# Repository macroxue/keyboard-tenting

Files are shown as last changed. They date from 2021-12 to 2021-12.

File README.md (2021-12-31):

# Continuously Variable Tenting (CVT)

This is a solution for flexible and reliable tenting of keyboards with very low
cost. Below is a short video showing it in action. A DIYer who has access to
3D-printing can easily build it and customize it.

https://user-images.githubusercontent.com/1887856/147719232-e44d4478-9f9e-47b6-bbbc-71b62043c802.mp4

## The Structure

The structure is essentially a steel plate on a
[ball joint](https://en.wikipedia.org/wiki/Ball_joint).
Any keyboard with magnets at the back can attach to the steel plate so it's a
universal platform. The ball joint allows the plate to rotate continuously in
a certain range so it's easy to tent and tilt the keyboard to one's liking.

## Parts

 * One 6"x12" stainless steel sheet, 0.03" or slightly thicker
 * Two 3D-printed ball joints
 * Four 1.25" binder clips
 * Eight 10mm disc magnets or two refrigerator magnets of playing card size

## Tools

 * A ruler and a pen
 * Heavy duty scissors
 * A file or sandpaper
 * 3D printer
 * Paper
 * Super glue
 * A candle and a lighter
 * Tape

## Installing Magnets

For a quick experiment, refrigerator magnets can be taped to the back of the
keyboard. 

For a permanent installation, I electric-taped disc magnets inside the keyboard's 
case, one at each corner. It works perfectly since the case has a thin (1.5mm) 
bottom and is very light. A large/heavy keyboard may need more or larger magnets. 
Have magnets oriented the same way, all north poles up or all north poles down. 

Test the installation on the steel sheet, vertically and upside down. If
needed, a few magnets can be attached to the back side of the sheet to help the
keyboard stay in place.

## Cutting the Steel Sheet

The plate can be of any shape/size as long as the keyboard can stay on it. (One can
even repurpose steel salad plates for this.) For simplicity, I would just go with a 
rectangle with rounded corners, because that's about as much as I could do using 
heavy duty scissors. Use a ruler and a pen to mark the line to cut. Be careful that
the sheet could be too hard to cut or too easy to distort. Test-cutting near
the edge could be a good idea. Be sure to file/sand down the rough edges afterwards.

By default, the model assumes the plate is 6 inches in length and shorter in width.
If a significantly larger geometry is desired, one needs to change the 3D model
in [cvt.scad](https://github.com/macroxue/keyboard-tenting/blob/master/cvt.scad)
accordingly to avoid the plate touching the desk when tented at the maximal angle.

## Printing the Ball Joint

ball-joint

Print either [cvt-35.stl](https://github.com/macroxue/keyboard-tenting/blob/master/cvt-35.stl)
for 35 degree of tenting maximally or
[cvt-45.stl](https://github.com/macroxue/keyboard-tenting/blob/master/cvt-45.stl) for 45
degree. The 35-degree one is slightly shorter than the 45-degree one, if that
matters. Each print produces three pieces for one hand, so the same model needs
to be printed twice. It takes about 12 hours to finish two prints on my
FlashForge Creator Pro.

My prints are with ABS filament. Other material should work too but I didn't
verify. A bit later melted wax will go into the socket so the material must
withstand the heat and not deform.

One can also modify [cvt.scad](https://github.com/macroxue/keyboard-tenting/blob/master/cvt.scad)
to customize the print, which is rendered by [OpenSCAD](https://openscad.org/). Please pay attention to
comments in the model and visually examine the rendered output for any issues
with structural integrity. The ball may need supports near the base if the
overhang is more than 45 degree. It can be a good idea to test-print a 50% model
after significant changes.

The two socket pieces may need to be polished to close the socket well.
Clamp the two pieces together by the binder clips. If the socket wobbles on
a smooth surface when slightly touched, it should be fixed and the protruding
parts can be scratched off by a knife. This usually happens around the edge
touching the printer's bed.

50-percent

## Gluing the Ball to the Plate

Put the ball at the center of the plate and wrap a paper stripe (1" to 2" wide)
around it.  Tape the paper cylinder to the plate and take the ball out.
Drop the ball with the flat side down into the cylinder and it should land
perfectly at the desired location. Apply super glue to the flat side and drop
the ball the same way again. Press the ball down slightly so the glue is more
evenly distributed.  Let it sit for a minute and the ball is permanently glued
to the plate.

## Waxing the Socket

Put all things together, the ball in the socket and the socket clamped by
binder clips. Try turning the plate to see how tight the joint is. Most likely
it's a bit loose. If so, take the ball out and light a candle. Drip melted wax
into the socket and spread it on the surface. If the socket can't close well
after this, just scratch some wax off. Test the tightness and repeat until it's
about right.

## Stablizing the Joint

All 3D-printed objects are slippery on a smooth surface. My solution is to put
the joint on a rubber mat. Another way is to rubber-coat its bottom with Plasti
Dip, but the process could be a little hazardous, requiring mask and glove protection.

## Tenting the keyboard

Put the keyboard on the plate. Adjust the orientation of the keyboard by
rotating the ball joint like how it's done in the video and see if any fine
tuning is needed.

To find the most comfortable position, one can quickly move or rotate the keyboard
on the plate without adjusting the ball joint every time.

Decorate them to show some personality if you like.

launch

## Acknowledgment

Many thanks to reditters of [r/ErgoMechBoards](https://www.reddit.com/r/ErgoMechKeyboards/)
who contributed to the discussion of the design in these threads.
* https://www.reddit.com/r/ErgoMechKeyboards/comments/ropcwq/continuously_variable_tenting_ball_joint_steel/
* https://www.reddit.com/r/ErgoMechKeyboards/comments/rqv95e/a_prototype_of_cvt_continuously_variable_tenting/

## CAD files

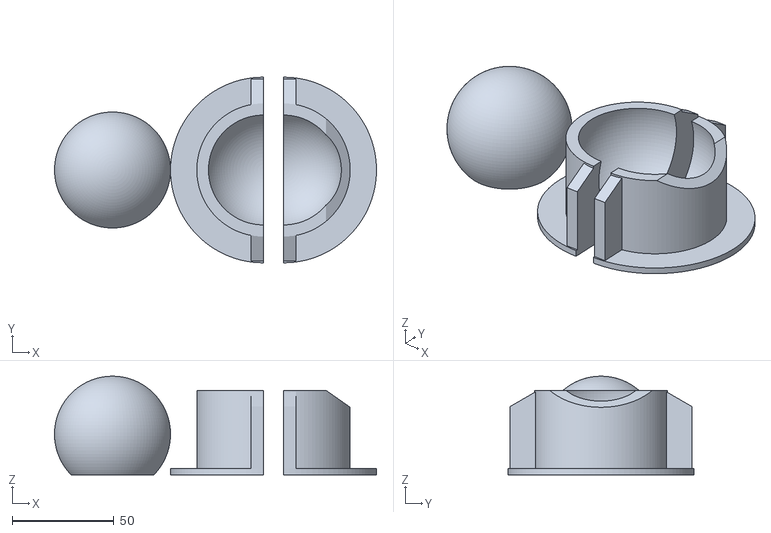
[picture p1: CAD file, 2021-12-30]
cvt-35.stl
158.6 x 91.4 x 48.6

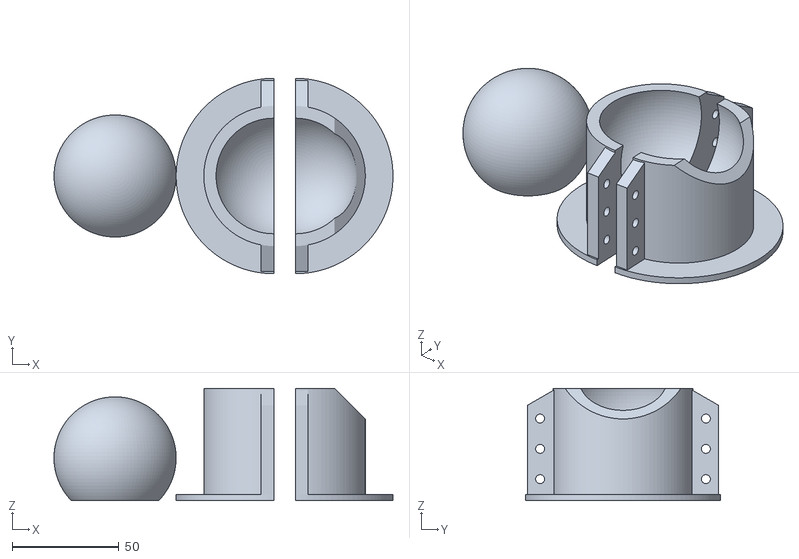
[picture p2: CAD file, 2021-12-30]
cvt-45.stl
158.6 x 91.4 x 52.6

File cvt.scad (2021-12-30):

// Higher tenting degree may produce a taller structure.
max_tenting_degree = 35;

// Plate to attach to the ball.
plate_length = 25.4 * 6;
plate_width = 25.4 * 4.5;

// The ball in the ball joint. A larger ball provides better stability but increases
// the height of the structure.
ball_radius = 25.4 * 1.125;
// The plateau supporting the plate. If the area is too small, the plate may flex.
// The default gives about 45 degree overhang at the base so it can be printed
// without supports.
ball_cut_ratio = 0.3;
ball_plateau_height = ball_radius * (1 - ball_cut_ratio);

// The lowest point that the plate can reach, assuming the plate is not rotated
// on the Z-axis. This inputs to the socket's height.
plate_lowest_z = plate_length / 2 * sin(-max_tenting_degree) +
                 ball_plateau_height * cos(-max_tenting_degree);

// Space between the ball and the socket. Could be 0 if the printer is very precise.
// Here we just want the socket to close well around the ball.
space = 0.2;

// Geometry of the socket.
socket_radius = ball_radius + space;
socket_closing_degree = 20;  // to prevent the ball from escaping
socket_thickness = 4;
socket_depth = socket_radius * (1 + sin(socket_closing_degree));
socket_height =
    max(socket_radius, -plate_lowest_z) + socket_radius * sin(socket_closing_degree);
socket_base_height = socket_height - socket_depth;

// The disc at the bottom to provide stability.
disc_radius = ball_radius * 1.6;
disc_thickness = 3;

// The number of sides to render a circle.
$fn = 100;
// The extra cut for difference() so the cut is unambiguous.
d = 0.1;
// Pseudo-infinity for splitting the socket into two parts.
inf = 999;

module plate(height = socket_radius) {
  translate([ -plate_length / 2, -plate_width / 2, ball_plateau_height ])
      cube([ plate_length, plate_width, height ]);
}

module ball() {
  difference() {
    sphere(r = ball_radius);
    translate([ 0, 0, ball_plateau_height ])
        cylinder(r = ball_radius, h = ball_radius * ball_cut_ratio);
  }
}

module socket() {
  difference() {
    translate([ 0, 0, -socket_radius - socket_base_height ]) union() {
      cylinder(r = socket_radius + socket_thickness, h = socket_height);

      // Ledges for binder clips.
      ledge_length = socket_thickness * 3;
      ledge_width = socket_thickness * 4;
      for (degree = [ 0, 180 ]) {
        rotate([ 0, 0, degree ])
            translate([ -ledge_length / 2, -socket_radius - ledge_width, 0 ]) {
          difference() {
            cube([ ledge_length, ledge_width, socket_height ]);
            translate([ -d, 0, socket_height - ledge_width * sin(30) ])
                rotate([ 30, 0, 0 ])
                    cube([ ledge_length + d * 2, ledge_width, socket_height ]);
          }
        }
      }
    }
    sphere(r = socket_radius);
    rotate([ 0, max_tenting_degree, 0 ]) plate();
  }
  translate([ 0, 0, -socket_radius - socket_base_height ]) disc();
}

module socket_left() {
  difference() {
    socket();
    translate([ 0, -inf / 2, -inf / 2 ]) cube([ inf, inf, inf ]);
  }
}

module socket_right() {
  difference() {
    socket();
    translate([ -inf, -inf / 2, -inf / 2 ]) cube([ inf, inf, inf ]);
  }
}

module disc() {
  translate([ 0, 0, -disc_thickness ]) cylinder(r = disc_radius, h = disc_thickness);
}

module pieces() {
  translate([ 0, 0, -ball_radius * ball_cut_ratio - socket_base_height ])
      rotate([ 180, 0, 0 ]) ball();
  translate([ disc_radius + ball_radius, 0, disc_thickness + space ]) socket_left();
  translate([ disc_radius + ball_radius + 10, 0, disc_thickness + space ]) socket_right();
}

module assembly(tent = max_tenting_degree, tilt = 0) {
  rotate([ 0, tent, 0 ]) rotate([ 0, 0, tilt ]) {
    ball();
    plate(1);
  }
  socket();
}

module animation() { assembly($t * max_tenting_degree, $t * -30); }

// Pieces to be printed.
translate([ plate_length / 2 + ball_radius, 0, 0 ]) pieces();

// Uncomment to see the assembly of pieces.
// assembly();

// Uncomment to see the rotating plate with OpenScad's "Animate" view.
// animation();

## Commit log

2021-12-30 Add model files
    [cvt-35.stl, cvt-45.stl, cvt.scad]
2021-12-30 Add a picture of 50% test print
2021-12-30 File down the rough edges of the plate
2021-12-31 Use refrigerator magnets for a quick experiment
2021-12-31 Possibly repurpose household plates
